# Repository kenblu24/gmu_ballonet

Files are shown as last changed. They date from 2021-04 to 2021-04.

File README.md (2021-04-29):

# gmu_ballonet

This is the repository for a Senior Design project. We are working on a ballonet for an autonomous blimp, along with control software to keep the blimp at a set level.

This project runs on an ESP32 running micropython. The repo also contains design files for 3D printed parts used to build the final product.

# Using github

Git is version control software. It is designed to help multiple people update code. Github is a service that hosts Git repositories.

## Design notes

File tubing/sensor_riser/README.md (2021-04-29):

# Sensor bumper/mount

This object can be 3D-printed.
It serves to rigidly mount
a GY-291 ADXL345,
a CLJVL53L0XV2, and
a MaxBotix MB1240-000 to a common surface.
The flexible portion allows the mount to flex should it bump into the floor.
No post-processing is needed.

The holes accept M2.5 screws.

------
Supports should not be used.
0.1mm layer height recommended.
PLA or PETG recommended.
Print slowly so that screw holes fully form.
If screw holes are too large, try increasing extrusion ratio.

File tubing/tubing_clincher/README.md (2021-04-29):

# 3/16 OD | 1/8 ID tubing clincher

This object can be 3D-printed.
It can be used to press-fit tubing 3/16 OD (\~5mm) onto a drafted 1/8 male non-barbed nipple.
No post-processing is needed.

To install this on tubing, make a cut along the tubing, about 10mm long.
Make a similar cut about 2mm around the tube.
Pull the resulting nib of tubing off.

Pull the tubing through the clincher. Needlenose pliers may help.
Cut away the excess tubing, leaving at least 3mm left outside the clincher.

To use, simply press the end of the tubing onto the nipple.
The clincher will help form a seal around the nipple.

------
Print standing up. 0.1mm layer height recommended for 0.4mm nozzle.
PLA recommended.

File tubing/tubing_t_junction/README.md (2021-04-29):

# 3/16 OD | 1/8 ID tubing tee junction

This object can be 3D-printed.
Three ends of tubing 3/16 OD (\~5mm) can be inserted to connect them.
Post-processing is needed.

The ID of the holes on the part is 4.5mm or smaller.
A drill bit is needed to create the correct ID.
Drilling also creates a smoother surface for an airtight seal.

Drill perpendicular to the hole.
Drill slowly to reduce chance of print cracking.

To use, simply pinch the end of the tube, and smoosh it into the hole.
Twist and pinch the tubing to insert it into the hole.
Give the tubing a gentle tug to ensure it is snug.

To remove, simply pull on the tubing.

------
This should be printed with the third port facing up.
Supports should not be used.
0.1mm layer height recommended.
PLA or Nylon recommended.

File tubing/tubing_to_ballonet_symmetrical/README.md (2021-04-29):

# 3/16 OD | 1/8 ID tubing to ballonet

This object can be 3D-printed.
Three ends of tubing 3/16 OD (\~5mm) can be inserted, forming a seal.
This can be taped between two layers of mylar balloon to form a seal.
Post-processing is needed.

The ID of the holes on the part is 4.5mm or smaller.
A drill bit is needed to create the correct ID.
Drilling also creates a smoother surface for an airtight seal.

Drill perpendicular to the hole.
Drill slowly to reduce chance of print cracking.

To install this in a balloon, place this at the entrance to the balloon.
About half of it should stick out.
Using packing tape or scotch tape, nudge a long piece of tape under the mylar.
Try not to wrinkle the balloon mylar, as this will allow air to leak.
Place a second piece of tape over the top ridge of the printed part.
The tape should have plenty of contact with both the printed part and the mylar.
Press the filleted surfaces of the part to form the seal.
Press the tape together to form the seal.
An example of what the finished product should look like is given in the report.

To use, simply pinch the end of the tube, and smoosh it into the hole.
Twist and pinch the tubing to insert it into the hole.
Give the tubing a gentle tug to ensure it is snug.

To remove, simply pull on the tubing.

------
This should be printed with the smaller hole touching the build plate.
Supports should not be used.
0.1mm layer height recommended.
PLA or Nylon recommended.

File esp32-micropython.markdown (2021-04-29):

---
layout: page
title: ESP32 MicroPython Installation Guide for 492
---
# Intro
This is a guide for how to get up and running with MicroPython on a common ESP32 development board. The guide will be similar to the official Micropython guide for [Getting started with MicroPython on the ESP32](http://docs.micropython.org/en/latest/esp32/tutorial/intro.html#esp32-intro).

# What's MicroPython?

MicroPython is a software implementation for Python 3 adapted for microcontrollers. You have most of the features of Python 3, plus some device-specific APIs for I.O. like for GPIO and SPI and stuff.

Read more about it here: https://micropython.org/

Or check out the official documentation here: http://docs.micropython.org/en/latest/

# Prerequisites:
To start, you'll need to have Python 3 installed. If you don't have Python 3, get it here: https://www.python.org/downloads/ . Make sure Python is in your PATH.

I'm assuming you're running Windows. If you're running Linux, you probably know how to translate commands to a Linux equivalent. I.e. call `python3` and `pip3` instead of `python` or `pip` since `python` might default to Python 2 (check with `python --version`). Use `screen` or a serial console to `/dev/ttyS0` instead of PuTTY to `COM1`, etc.

# Installing the MicroPython firmware

### Installing esptool

You'll need Espressif's [esptool](https://github.com/espressif/esptool/) to flash the bootloader on your ESP32.

Once you know Python is installed, open CMD or your choice of terminal and type `pip install esptool`.



To check whether esptool was installed, run `esptool.py` in your terminal. You should get the esptool version and help.



### Downloading and installing MicroPython

You'll need to download the binary for the firmware for the ESP32. Here's the download page: https://micropython.org/download/esp32/

I am using the latest stable GENERIC build with support for BLE, LAN, and PPP. At the time of writing, that is [esp32-idf3-20200902-v1.13.bin](https://micropython.org/resources/firmware/esp32-idf3-20200902-v1.13.bin).

Note: **THE FOLLOWING STEPS WILL ERASE ANYTHING STORED ON THE ESP32**. You can restore the original ESP-IDF firmware later using their development environment.

In your terminal, navigate to the folder where you put the .bin file. If you have the folder open in Windows File Explorer, you can click on the address bar, type `cmd`, and hit enter. This will open a command prompt at the current path of the Explorer window.

You will need to find the serial address of your ESP32 board on your computer. Connect your ESP32 to your computer using a micro-USB cable. Then, open *Device Manager*. You can do this quickly by right-clicking on the Start button and choosing *Device Manager*. Then, find the section titled *Ports (COM & LPT)* and expand it. Your ESP32 will be listed in this section. Figure out which one it is. The entry will have the serial COM port number listed next to it. For example, in the picture below, my ESP32 is on `COM5`.



To erase the flash, in your terminal, enter `esptool.py --port COM5 erase_flash` where `COM5` is replaced with the serial address of your ESP32.



Then, to write the firmware, enter `esptool.py --chip esp32 --port COM5 write_flash -z 0x1000 esp32-idf3-20200902-v1.13.bin`

You will need to replace the `COM5` with the serial port you found earlier. Replace the last argument, `esp32-idf3-20200902-v1.13.bin`, with the file name of the firmware that you downloaded earlier. Remember that you should be running this in the same directory as the firmware file.

The esptool.py will flash the ESP32 with the MicroPython firmware and verify that it was written correctly.



Congratulations! MicroPython should now be installed on your ESP32!

# Getting a REPL Prompt

MicroPython is an interpreted language with its own REPL prompt. We can get an interactive prompt that runs off our ESP32 and run commands right on the microcontroller! We're going to do this through a serial connection first.

Open PuTTY. For *Connection type:*, choose `Serial`. For *Serial line*, type in the COM port you found earlier. In my case, it's `COM5`. For *Speed*, use a baud rate of `115200`.



Click *Open*. PuTTY should connect to your ESP32 and you should see something like this:



If so, try typing `print("Hello, world!")` and hit enter. You should get a response back.



Congrats! You've just run MicroPython on your ESP32! If you really wanted to, you could write a whole program like this.

# File transfer

Okay, but how do we run .py files on the ESP32? Well, first, we need a way to transfer files to the board. [This article](https://www.digikey.com/en/maker/projects/micropython-basics-load-files-run-code/fb1fcedaf11e4547943abfdd8ad825ce) mentions several methods of doing so, like the web REPL, which can be accessed over Wi-Fi, rshell, and mpfshell. But it explains how to use Adafruit's **ampy** tool over a serial USB connection to do so. We've already got our ESP32 plugged in, so let's try that.

Go back to your terminal, and run `pip install adafruit-ampy`. The tool should then install.

To verify that the tool works, run `ampy` in your terminal. You should get the help file.

Let's try transfering a file. First, we need a file to run. Make a file called `hello.py` and put the following line in it: `print("Hello again!")`

Then, open a terminal at the location of the `hello.py` file and run `ampy --port COM5 put hello.py`. This will transfer the `hello.py` file to the root directory of your ESP32's file system, overwriting any existing hello.py file.

**Note: Only one program can open the serial connection to your ESP32 at a time. If you still have a PuTTY connected to your ESP32, close it!**

Now, try running the file. In your terminal, run `ampy --port COM5 run hello.py`. You should see a response.

Congrats! You've just transferred a file to your ESP32! For more info on the `ampy` tool, check out the article linked above. Or just run `ampy` in your terminal for a quick refresher.

# Other topics

Other workflow things you can try include setting up your ESP32 to connect to your Wi-Fi, which will allow you to access the webREPL prompt and upload files to the ESP32 without a serial connection.

# Wi-Fi and WebREPL setup overview

Follow the instructions in the [Networking section of the MicroPython ESP32 quick reference](http://docs.micropython.org/en/latest/esp32/quickref.html#networking) to get your ESP32 connected to the Wi-Fi. Download the `boot.py` file from your ESP32 using `ampy` or something. Add the code from the Networking section to the `boot.py` so that it runs when the ESP32 starts up.

Follow the instructions in the [WebREPL section](http://docs.micropython.org/en/latest/esp32/quickref.html#webrepl-web-browser-interactive-prompt) and add the code from this section to the `boot.py`. When you restart your ESP32, you will be able to connect to it using WebREPL.

You don't need to install a WebREPL client on your computer to connect to your ESP32. You can go here: http://micropython.org/webrepl **Note that this is an http:// connection. You can't connect to the ESP32 using an encrypted https:// connection.**

If you have multicast DNS enabled, you can connect to your esp32 by entering

# Running files using `import`

If you have the REPL prompt open, you can run a file simply by typing `import filename`. This will cause the entirety of `filename.py` to be executed. However, because the file has been imported, you can't import the file again without rebooting your ESP32. You can, however, work around this. See this thread:

https://forum.micropython.org/viewtopic.php?t=4192

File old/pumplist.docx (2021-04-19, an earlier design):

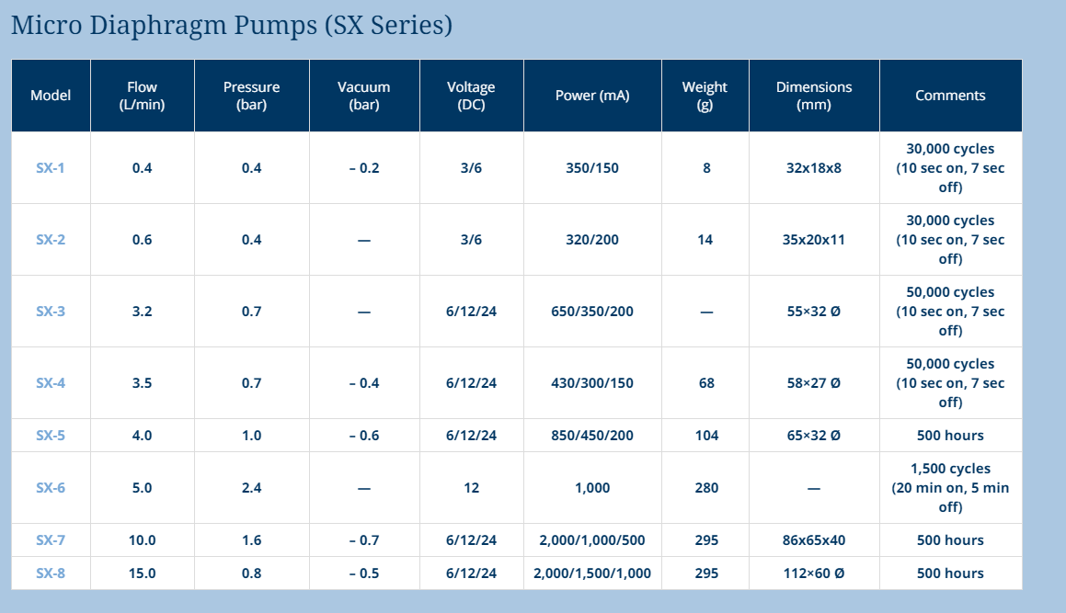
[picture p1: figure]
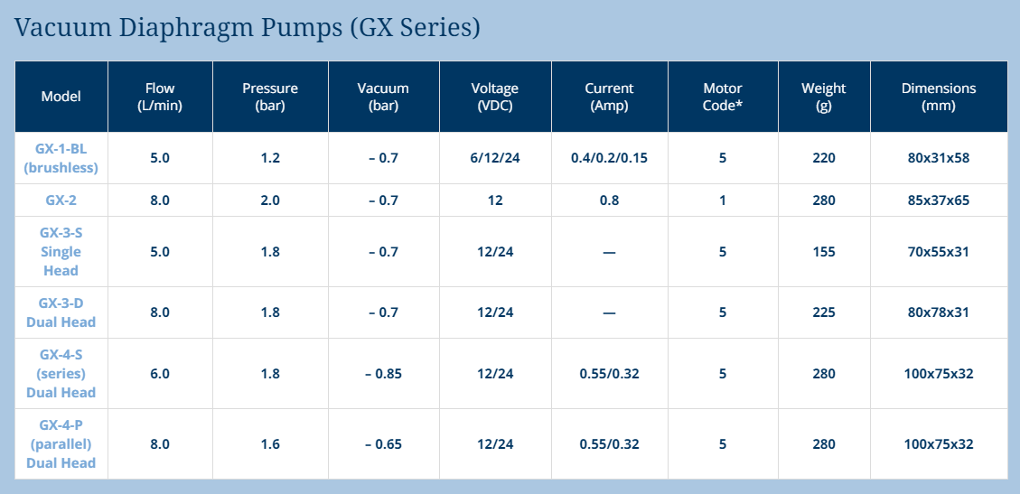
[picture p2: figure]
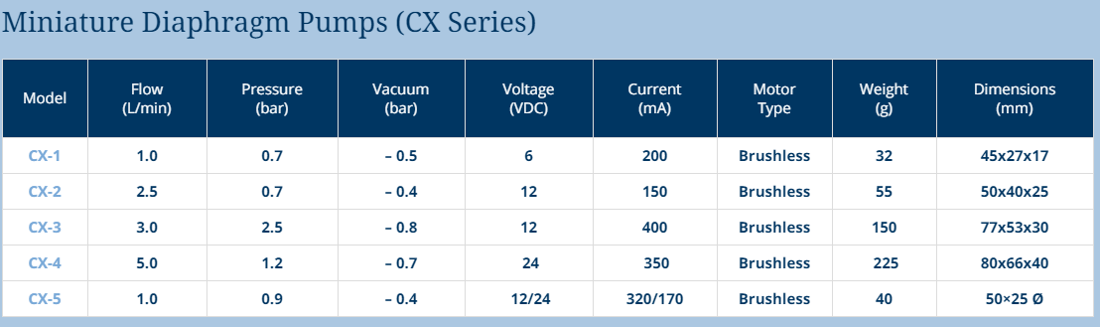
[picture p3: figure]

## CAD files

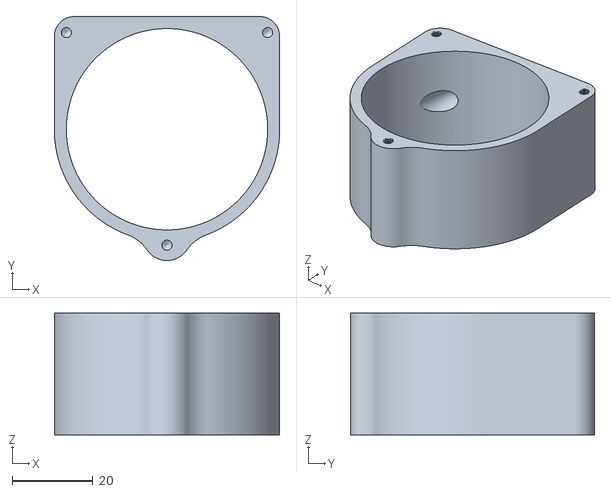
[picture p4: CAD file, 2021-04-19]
tubing/40mm_vane_pump/40mm_vane_pump_stl/mainbody.stl
56.0 x 60.6 x 30.2

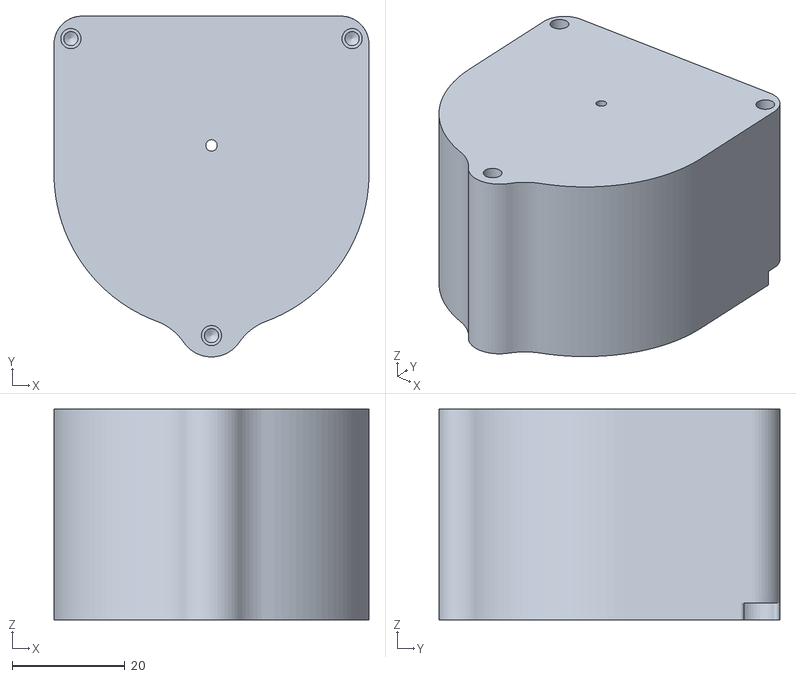
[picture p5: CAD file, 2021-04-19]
roots/vane_pump/vane pump 1 v4.stl
56.0 x 60.6 x 37.5

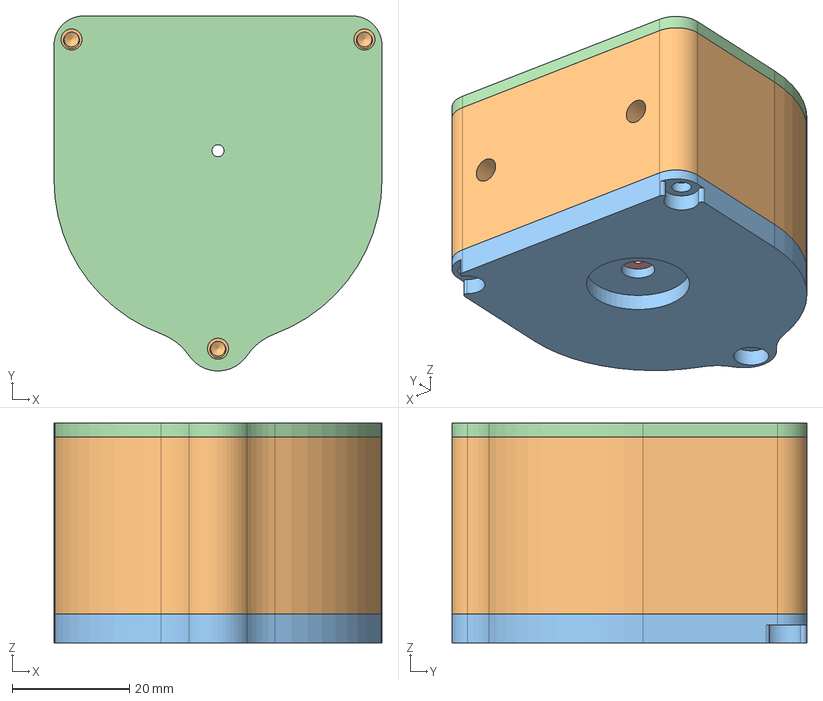
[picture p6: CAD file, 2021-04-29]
tubing/40mm_vane_pump/40mm_vane_pump.step
56.0 x 60.6 x 37.5 mm
vane
mainbody
motor_backplate
frontplate
rotor

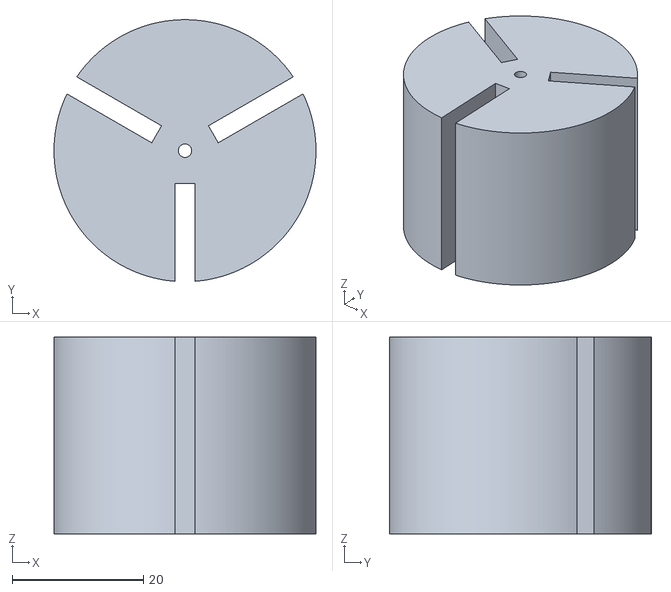
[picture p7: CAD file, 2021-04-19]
tubing/40mm_vane_pump/40mm_vane_pump_stl/rotor.stl
40.0 x 39.9 x 30.0

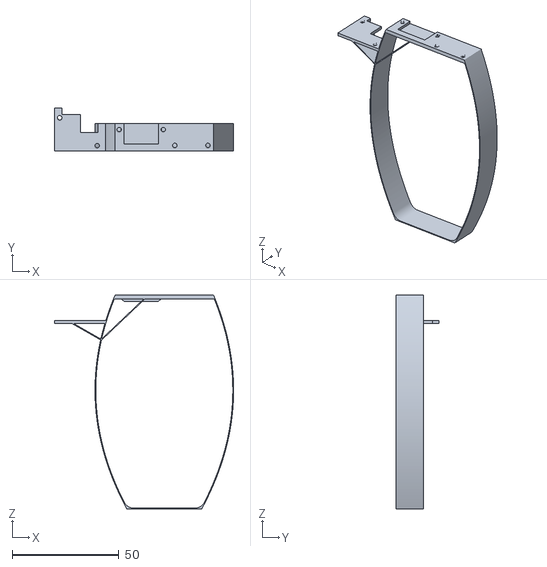
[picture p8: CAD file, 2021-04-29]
tubing/sensor_riser/sensor_riser.stl
83.8 x 20.0 x 100.0

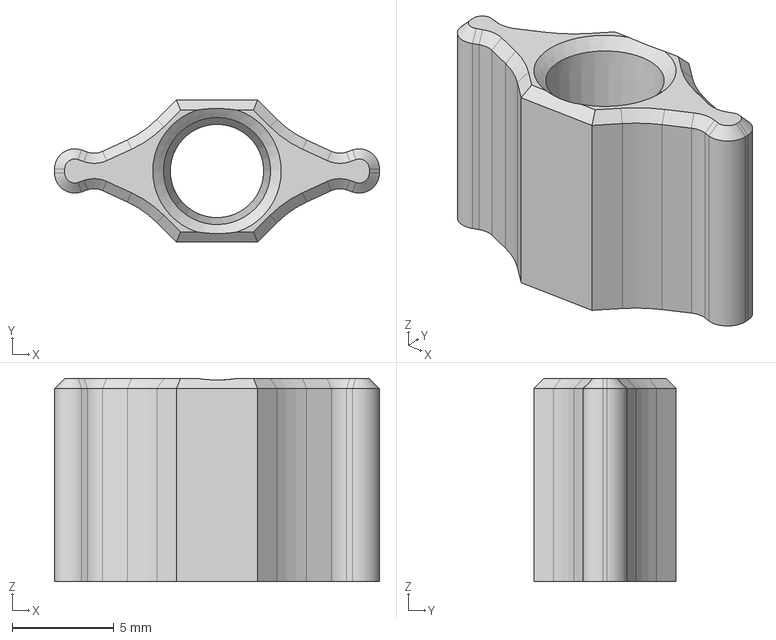
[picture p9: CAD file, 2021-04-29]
tubing/tubing_clincher/3-16OD tube clincher for 3mm pump v2.step
16.0 x 7.00 x 10.0 mm

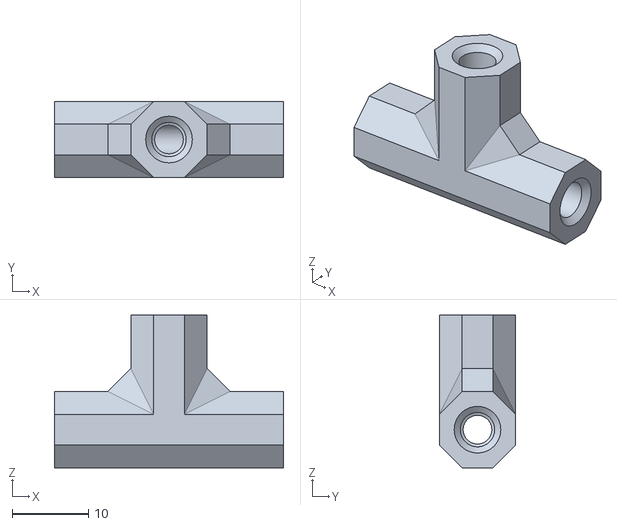
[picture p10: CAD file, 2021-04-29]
tubing/tubing_t_junction/tubing_t_junction.stl
30.0 x 10.0 x 20.0

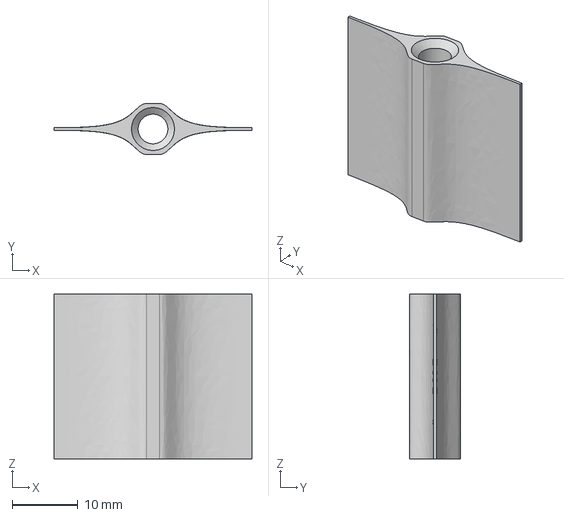
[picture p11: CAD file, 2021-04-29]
tubing/tubing_to_ballonet_symmetrical/hose_to_balloon_symmetrical v2.step
30.0 x 7.70 x 25.0 mm

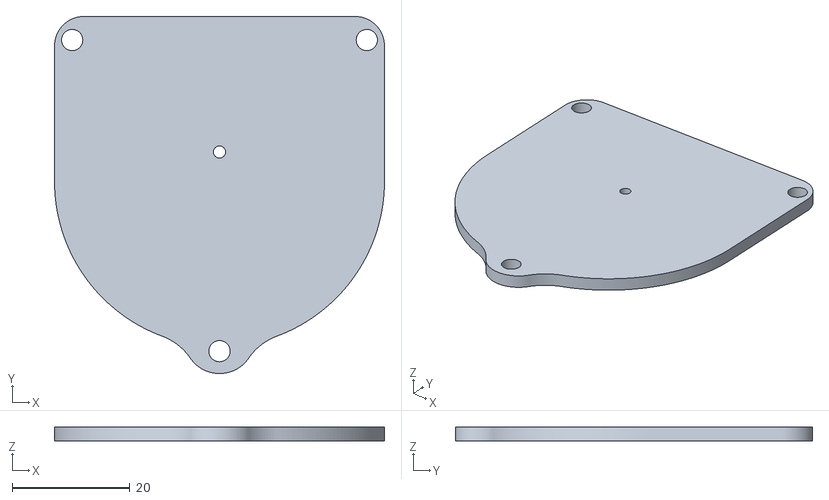
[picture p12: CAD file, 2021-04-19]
tubing/40mm_vane_pump/40mm_vane_pump_stl/frontplate.stl
56.0 x 60.6 x 2.40

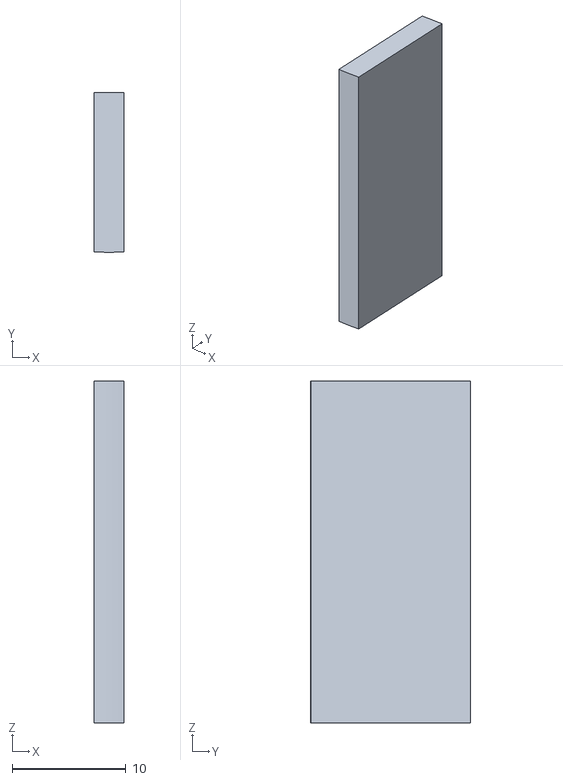
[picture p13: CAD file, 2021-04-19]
tubing/40mm_vane_pump/40mm_vane_pump_stl/vane.stl
2.60 x 14.0 x 30.0

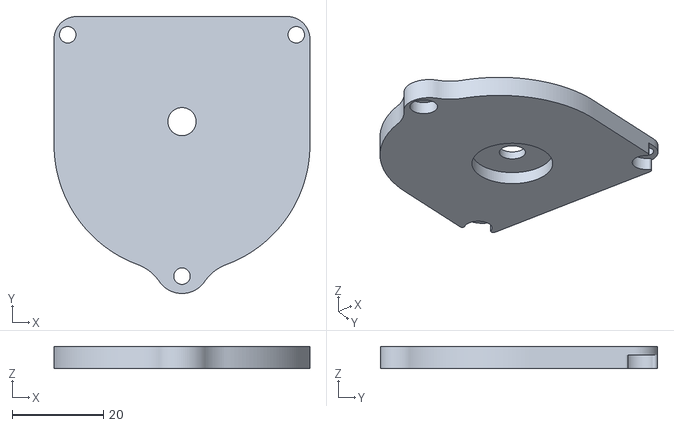
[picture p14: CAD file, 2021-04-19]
tubing/40mm_vane_pump/40mm_vane_pump_stl/motor_backplate.stl
56.0 x 60.6 x 4.90

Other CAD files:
tubing/sensor_riser/sensor_riser v4.step
tubing/tubing_clincher/tubing_clincher.stl
tubing/tubing_t_junction/5mm od tube t junction v3.step
tubing/tubing_to_ballonet_symmetrical/hose_to_balloon.stl
roots/housing.ipt
roots/roots_blower_1.iam
roots/roots_blower_1/Design Accelerator/Spur Gear12.ipt
roots/roots_blower_1/Design Accelerator/Spur Gear22.ipt
roots/roots_blower_1/Design Accelerator/Spur Gears2.iam
roots/roots_rotor_3lobe.ipt
tubing/40mm_vane_pump/40mm_vane_pump.f3d
tubing/sensor_riser/sensor_riser v4.f3d
tubing/tubing_clincher/3-16OD tube clincher for 3mm pump v2.f3d
tubing/tubing_t_junction/5mm od tube t junction v3.f3d
tubing/tubing_to_ballonet_symmetrical/hose_to_balloon_symmetrical v2.f3d

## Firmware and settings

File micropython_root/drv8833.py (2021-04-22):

from machine import Pin, PWM


# this class controls an individual channel (A or B) on the drv8833
# It is meant to be used as an internal class for the full driver
class MOTOR_BANK:
    def __init__(self, pwm_frequency, in1_pin, in2_pin, duty_callback=None):
        self._pwm_frequency = pwm_frequency
        # Warning! Index change. in1 is [0], in2 is [1]
        self.pins = (in1_pin, in2_pin)
        for pin in self.pins:
            # init both output pins as GPIO
            pin.init(Pin.OUT, value=0)
        # PWM object takes precedence over GPIO output of that pin
        self.out = [self.pins[0], PWM(self.pins[1], freq=pwm_frequency, duty=0)]
        self._direction = "Forward"
        self._duty = 0
        self._duty_int = 0
        self.duty_callback = duty_callback  # called when duty is changed
        # used for setting sleep when all motors off.

    @property
    def duty(self):
        return self._duty

    @duty.setter
    def duty(self, duty):
        # changes internal duty cycle and updates PWM output
        self._duty = duty
        self._duty_int = min(1023, max(0, int(duty * 1024)))
        # change duty cycle while preserving direction
        if type(self.out[0]) is PWM:
            self.out[0].duty(self._duty_int)
        elif type(self.out[1]) is PWM:
            self.out[1].duty(self._duty_int)

        try:
            self.duty_callback()
        except TypeError as e:
            if e == "'NoneType object isn't callable":
                pass
            else:
                raise e

    @property
    def direction(self):
        return self._direction

    @direction.setter
    def direction(self, direction):
        # logic to set pin config based on direction
        # See DRV8833 datasheet for more info
        if direction in ("Forward", "Forward Coast", "Reverse Brake"):
            if type(self.out[1]) is PWM:
                self.out[1].deinit()
            self.out[0] = PWM(self.pins[0], freq=self._pwm_frequency, duty=self._duty_int)
            self.out[1] = self.pins[1]
            if "Forward" in direction:
                self.out[1].off()
            elif "Reverse" in direction:
                self.out[1].on()
        elif direction in ("Reverse", "Reverse Coast", "Forward Brake"):
            if type(self.out[0]) is PWM:
                self.out[0].deinit()
            self.out[0] = self.pins[0]
            self.out[1] = PWM(self.pins[1], freq=self._pwm_frequency, duty=self._duty_int)
            if "Forward" in direction:
                self.out[0].on()
            elif "Reverse" in direction:
                self.out[0].off()
        else:
            raise Exception(str(direction) + " was not a valid direction.")

    @property
    def pwm_frequency(self):
        return self._pwm_frequency

    @pwm_frequency.setter
    def pwm_frequency(self, frequency):
        # changes internal pwm_frequency and updates PWM output
        self._pwm_frequency = frequency
        if type(self.out[0]) is PWM:
            self.out[0].freq(self._pwm_frequency)
        elif type(self.out[1]) is PWM:
            self.out[1].freq(self._pwm_frequency)


class DRV8833:
    def __init__(self, pwm_frequency, sleep_pin, fault_pin, in1_pin, in2_pin, in3_pin, in4_pin):
        # this class controls stuff between banks.
        self.sleep = sleep_pin  # Active LOW (DRV8833 enabled when HIGH)
        self.sleep.init(mode=Pin.OUT, value=0)
        self.fault = fault_pin  # NOT IMPLEMENTED but can read with this.fault.value
        self.fault.init(mode=Pin.IN)

        self.sleep.off()

        self.motor = dict()
        if in1_pin and in2_pin:
            self.motor['A'] = MOTOR_BANK(pwm_frequency, in1_pin, in2_pin, self.duty_callback)
        if in3_pin and in4_pin:
            self.motor['B'] = MOTOR_BANK(pwm_frequency, in3_pin, in4_pin, self.duty_callback)

    def emergency_stop(self):
        # Attempts to shut off all pins in all defined motor channels.
        # May require re-init to use motors afterwards.
        for motor in self.motor.values():
            for io in motor.out:
                if type(io) is PWM:
                    io.deinit()
                if type(io) is Pin:
                    io.off()
            for io in motor.pins:
                if type(io) is Pin:
                    io.init(Pin.OUT, value=0)
        print("Emergency Stop called.")

    def duty_callback(self):
        # set SLEEP pin HIGH if all motors off, else LOW
        all_off = True
        for motor in self.motor.values():
            if motor.duty is not 0:
                all_off = False
        self.sleep.value(int(not all_off))


if __name__ == '__main__':
    # drv8833(pwm_frequency, sleep_pin, fault_pin, in1_pin, in2_pin, in3_pin, in4_pin)
    hbridge = DRV8833(1000, Pin(32), Pin(33), Pin(25), Pin(26), Pin(27), Pin(14))
    # examples
    # duty cycle can be set between 0 to 1
    # hbridge.motor['A'].duty = 0.5
    # hbridge.motor['B'].direction = "Forward"
    # hbridge.motor['A'].pwm_frequency = 100

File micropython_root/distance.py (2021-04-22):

'''
Height tilt-correction for distance sensors using ADXL345 accelerometer

# class HeightTiltCompensator gives a tilt-corrected height measurement
# Ranging device may be VL53L0X using one of two device drivers
#  or Maxbotix XL-Maxsonar (UART)
# Accelerometer device must be ADXL345
# Uses angle of device compared to gravity vector to compensate height reading
'''

from time import sleep
import math

OUT_OF_RANGE = float('inf')
INVALID = float('-inf')


class HeightTiltCompensator:
    def __init__(self, accelerometer, ranging_device):
        self.accelerometer = accelerometer
        self.rangefinder = ranging_device
        self.offset = 0  # single-point calibration offset for ranging device
        # adjustment for cone beam compensation (edges of cone read closer)
        # without it, tilting further will cause compensated height to be low
        self.cone_adjust = 1  # value of 0 disables cone adjustment. 1 is max
        # maximum tilt allowed before distance measurement is marked invalid
        self.max_angle = math.radians(45)

        # set certain constants based on ID string in device driver class.
        try:
            self.type = ranging_device.DEVICE_TYPE
        except AttributeError:
            raise NotImplementedError("Object used for ranging_device has no DEVICE_TYPE.")
        if self.type == 'VL53L0X_ada':
            self.read = self.read_VL53L0X_ada
            self.MAX_RANGE = 1200
            self.MIN_RANGE = 5
            self.CONE_ADJUST = 0.5
        elif self.type == 'VL53L0X_polulu':
            self.read = self.read_VL53L0X_polulu
            self.MAX_RANGE = 2000
            self.MIN_RANGE = 5
            self.CONE_ADJUST = 0.5
            self.rangefinder.set_Vcsel_pulse_period(self.rangefinder.vcsel_period_type[0], 18)
            self.rangefinder.set_Vcsel_pulse_period(self.rangefinder.vcsel_period_type[1], 14)
            self.rangefinder.set_measurement_timing_budget(33000)  # API broken, this doesn't work
        elif self.type == 'XL-MAXSONAR':
            self.read = self.read_XLMAXSONAR
            self.start = self.start_XLMAXSONAR
            self.read_buffered = self.read_buffered_XLMAXSONAR
            self.MAX_RANGE = 7500
            self.MIN_RANGE = 200
            self.CONE_ADJUST = 0.8

    # this will be used if device is UART maxsonar type
    def read_XLMAXSONAR(self):
        self.start_XLMAXSONAR()
        sleep(0.1)
        return self.read_buffered_XLMAXSONAR()

    def start_XLMAXSONAR(self):
        self.rangefinder.start()

    def read_buffered_XLMAXSONAR(self):
        raw_distance = self.rangefinder.read()
        if raw_distance > 763:
            return OUT_OF_RANGE
        ranged_distance = max(raw_distance + self.offset / 10, 1)
        return self.tilt_compensation(ranged_distance) * 10

    # this will be used if device is serial maxsonar type
    def read_VL53L0X_ada(self):
        raw_distance = self.rangefinder.range
        if raw_distance > 8100:  # VL53L0X typically reads 8192 when out of range (too far)
            return OUT_OF_RANGE
        # calibration offset for TOF sensor
        ranged_distance = max(raw_distance + self.offset, 1)
        return self.tilt_compensation(ranged_distance)

    # this will be used if rangfinder is VL53L0X (polulu driver).
    def read_VL53L0X_polulu(self):
        self.rangefinder.start()
        # driver timings are broken in long-range, so need to call read() twice
        self.rangefinder.read()
        raw_distance = self.rangefinder.read()
        self.rangefinder.stop()
        if raw_distance > 8100:  # VL53L0X typically reads 8192 when out of range (too far)
            return OUT_OF_RANGE
        # calibration offset for TOF sensor
        ranged_distance = max(raw_distance + self.offset, 1)
        return self.tilt_compensation(ranged_distance)    # this will be used if rangfinder is VL53L0X (polulu driver).

    def get_angle_vertical(self):
        v = self.accelerometer.getAxes()
        dot_product = -1.0 * v['z']
        v_magnitude = math.sqrt(v['x']**2 + v['y']**2 + v['z']**2)
        return math.acos(dot_product / v_magnitude)

    def tilt_compensation(self, distance):
        theta = self.get_angle_vertical()
        # return invalid if we're not pointing mostly straight down
        if not 0.0 < theta < self.max_angle:
            return INVALID
        # cone correction scales the effect of tilt compensation with the distance read
        # This may need to be re-written; I don't think my math is right
        cone_correction = 1 - (min(distance, self.MAX_RANGE) / self.MAX_RANGE) * self.CONE_ADJUST
        distance = distance * math.cos(theta * cone_correction)
        return int(distance)


def main():
    global read  # make function global
    global this
    from machine import Pin, I2C
    import adxl345
    import VL53L0X
    import accelerometer
    i2c = I2C(0, scl=Pin(22), sda=Pin(21))
    adxl = adxl345.ADXL345(i2c, 83)
    a = accelerometer.ACCELEROMETER(adxl, 'adxl345_calibration_2point')
    tof = VL53L0X.VL53L0X(i2c, 41)
    this = HeightTiltCompensator(a, tof)
    this.offset = -50
    read = this.read  # make function callable (so we can call distance.read() )


if __name__ == "__main__":
    main()

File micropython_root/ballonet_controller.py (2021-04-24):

# TODO: implement temperature smoothing for thermal runaway protection
from micropython import const
import _thread
from time import sleep
import time

from statistics_tools import abs_fwd_timegraph, linreg_past

from bmp388 import BMP388
from VL53L0X import VL53L0X
from maxsonar import XLMaxSonarUART
from adxl345 import ADXL345
from accelerometer import ACCELEROMETER
from distance import HeightTiltCompensator
from altitude import ALTITUDE
import pump

_ALTITUDE_SAMPLING_TIME_BUDGET = 200  # sampling period of barometer in ms

# I2C Object
if 'i2c' not in globals():
    from machine import I2C, Pin
    i2c = I2C(0, scl=Pin(22), sda=Pin(21))

adxl = ADXL345(i2c, 83)
accelerometer = ACCELEROMETER(adxl, 'adxl345_calibration_2point')
tof = VL53L0X(i2c, 41)
tof_fusion = HeightTiltCompensator(accelerometer, tof)
ultrasonic = XLMaxSonarUART()
ultrasonic_fusion = HeightTiltCompensator(accelerometer, ultrasonic)
barometer = BMP388(i2c)

altitude = ALTITUDE(barometer, tof_fusion, ultrasonic_fusion)
altitude.sr.offset = -40.0

_MAX_LIST_SIZE = const(120)

CFGFILE = "ballonet_controller_cfg"

cfg = {
    'setpoint': 0,  # maintain this velocity
    'bangbang_tolerance': 50,  # mm/s, activate pump above this speed

    # when above ceiling height, decrease velocity setpoint
    # it may be good to set this well under max range of LR rangefinder
    # set to float('inf') to disable
    'ceiling_height': 120,

    # when below floor height, increase velocity setpoint
    # set to float('-inf') to disable
    'floor_height': 0,

    # noise scaling will widen the bangbang tolerance if noise is detected
    'noise_scaling': False,

    # see altitude.py file for info on these
    'barometer_drift': 1,
    'calibration_drift': 0.25
}


def loadcfg():
    with open(CFGFILE, 'r') as f:
        text = f.read().rstrip().split("\n")
        for i in text:
            key, value = i.split("\t")
            cfg[key] = eval(value)
    altitude.barometer_drift = cfg['barometer_drift']
    altitude.calibration_drift = cfg['calibration_drift']


def savecfg():  # only dicts with string keys and stringable values are supported
    # sadly pickle module not available in micropython yet :(
    with open(CFGFILE, 'w') as f:
        for key in cfg:
            f.write("{key}\t{value}\n".format(key=key, value=str(cfg[key])))


def __loop(n_s, T):
    global enable
    global history
    # Length of history to use for calculating velocity
    history = {'altitude': [], 'velocity': [], 'time': []}
    previous_time = time.ticks_ms()
    for i in range(n_s + 1):
        history['altitude'].append(altitude.meters)
        now = time.ticks_ms()
        history['time'].append(time.ticks_diff(now, previous_time))
        previous_time = time.ticks_ms()
        history['velocity'].append(0)
        sleep(0.3)
    i = 0
    while True:
        if not enable:
            pump.emergency_stop()
            print("Stopping!")
            _thread.exit()
            return
        setpoint = cfg['setpoint']
        h = history['altitude']
        t = history['time']
        fix_push(h, 0.5 * altitude.meters + 0.5 * h[-1])
        now = time.ticks_ms()
        fix_push(t, time.ticks_diff(now, previous_time))
        previous_time = time.ticks_ms()
        velocity = linreg_past(abs_fwd_timegraph(t, len(t) - n_s),
                               h,
                               n_s)[0]
        # convert velocity from weird units to mm/s
        velocity = int(velocity * 1000 * 1000 / (sum(t[-n_s:]) / 1000))
        fix_push(history['velocity'], velocity)

        if h[-1] < cfg['floor_height']:
            setpoint += 50
        elif h[-1] > cfg['ceiling_height']:
            setpoint -= 50
        e = velocity - setpoint  # +e is the velocity above the setpoint
        pwm_duty = 1
        if abs(e) > cfg['bangbang_tolerance']:
            if e > 0:  # velocity too upwards
                pump.pump_in(pwm_duty)  # reduce buoyancy
            elif e < 0:  # velocity too downwards
                pump.pump_out(pwm_duty)  # increase buoyancy
        else:
            pump.stop()
        print("{:3}| T: {:3d}, H: {:7.3f}, V: {:4d}".format(i, t[-1], h[-1], history['velocity'][-1]))
        i += 1
        sleep(T)


def calibrate(barometer_drift=1, calibration_drift=0.25):
    altitude.find_floor_from_range(10, True)


def start(n_s=5, T=1000):
    global enable
    global loop
    enable = True
    T_adjusted = T - _ALTITUDE_SAMPLING_TIME_BUDGET  # this is in ms
    loop = _thread.start_new_thread(__loop, (n_s, T_adjusted / 1000))


def stop():
    global enable
    global loop
    enable = False


def setpoint(velocity):
    global setpoint
    setpoint = velocity


def fix_push(o, value, max_size=_MAX_LIST_SIZE):
    if len(o) + 1 > max_size:
        o.pop(0)
    try:
        o.append(value)
    except MemoryError:
        pump.emergency_stop()
        raise

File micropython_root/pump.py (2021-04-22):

from machine import Pin
from drv8833 import DRV8833

# args: pwm_frequency, sleep_pin, fault_pin, in1_pin, in2_pin, in3_pin, in4_pin
hbridge1 = DRV8833(1000, Pin(32), Pin(33), Pin(25), Pin(26), Pin(27), Pin(14))
hbridge2 = DRV8833(1000, Pin(15), Pin(2), Pin(4), Pin(16), Pin(17), Pin(5))


# H-Bridge 1 Motor A: In pump
# H-Bridge 1 Motor B: Out pump

# H-Bridge 2 Motor A: Exhaust valve
#   (NC, check adafruit doc for pneumatic connections)

def pump_in(duty=1):
    hbridge1.motor['A'].duty = duty
    hbridge1.motor['B'].duty = 0
    hbridge2.motor['A'].duty = 0


def pump_out(duty=1):
    hbridge1.motor['A'].duty = 0
    hbridge1.motor['B'].duty = duty
    hbridge2.motor['A'].duty = duty


def stop():
    hbridge1.motor['A'].duty = 0
    hbridge1.motor['B'].duty = 0
    hbridge2.motor['A'].duty = 0


def emergency_stop():
    hbridge1.emergency_stop()
    hbridge2.emergency_stop()

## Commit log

2021-03-04 init commit
    [ballonet.kicad_pcb, ballonet.sch, epcos100k.tsv]
2021-03-28 added roots blower CAD files
    [Spur Gear12.ipt, Spur Gear22.ipt, Spur Gears2.iam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]
2021-03-29 overhauled drv8833 driver
2021-04-02 added pump.py
2021-04-04 added stop function to pump.py
2021-04-08 Update velocity.py
    Corrected logic to correctly use only z element of velocity vector, and simplified the logic. Also corrected velocity to be a vector, not an integer.
    [velocity.py]
2021-04-19 added 40mm vane pump files
    [ballonet_esp32_proto.sch, clincher.stl, frontplate.stl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]
2021-04-19 fix file capitalization error
    [bmp388.py]
2021-04-19 Turned bmp388 driver into a Class; added altitude.py
2021-04-20 implemented velocity tracking using least-squares linreg
2021-04-21 allowed distance.py to work with multiple rangefinders, implemented live calibration
2021-04-29 updated schematic
    [ballonet_esp32_proto.sch, clincher.stl]
2021-04-29 added 3D printing CAD files and STLs
    [3-16OD tube clincher for 3mm pump v2.f3d, 3-16OD tube clincher for 3mm pump v2.step, 40mm_vane_pump.f3d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]
2021-04-29 esp32 installation guide
